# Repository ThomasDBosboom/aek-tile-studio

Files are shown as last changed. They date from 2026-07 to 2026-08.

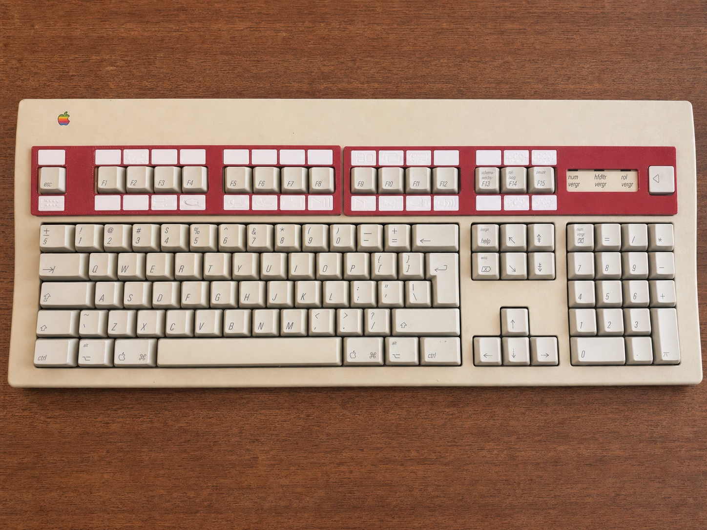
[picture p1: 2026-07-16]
assets/images/aek-tile-studio-installed-prototype-v2.jpg

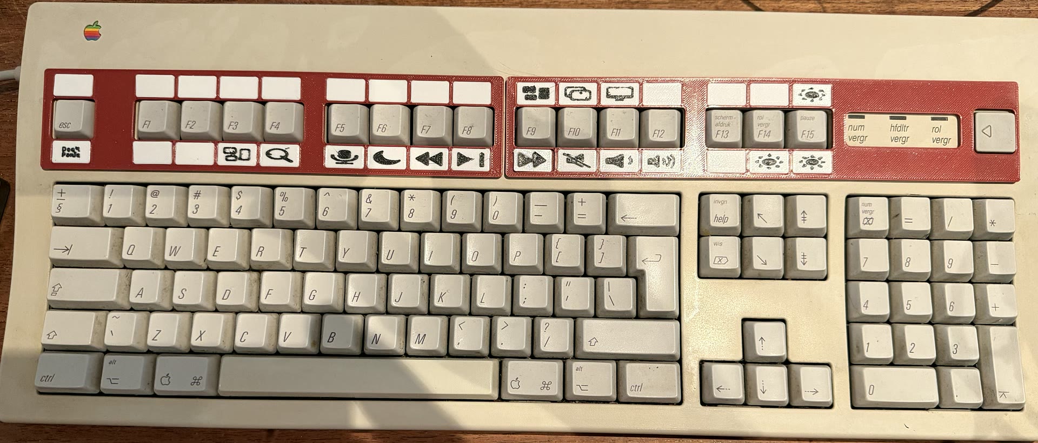
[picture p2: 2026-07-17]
assets/images/aek-tile-studio-installed-prototype-v3.jpg

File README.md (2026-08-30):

# AEK Tile Studio

A static, client-side prototype for arranging and generating modular legend
tiles for the Apple Extended Keyboard II.

##public page

https://thomasdbosboom.github.io/aek-tile-studio/

## Run your own - Local preview

Run a static HTTP server from this directory; ES modules and SVG loading do
not work reliably through `file://` URLs.

```sh
python3 -m http.server 8080 --directory site
```

Then open <http://localhost:8080>.

## Geometry

- Tile: 17.4 × 10.2 × 1.7 mm
- Medium fit: 0.10 mm clearance per side in the rev10 frame
- Top chamfer: 0.25 mm
- Default symbol relief: 0.40 mm

The browser generator exports binary STL using Three.js. Glyph and tile meshes
overlap slightly so slicers treat them as one printable body. Validate a test
tile in your slicer before committing to a full plate.

## Publishing

The `site` directory is suitable for GitHub Pages. It has no build step and no
server-side component.

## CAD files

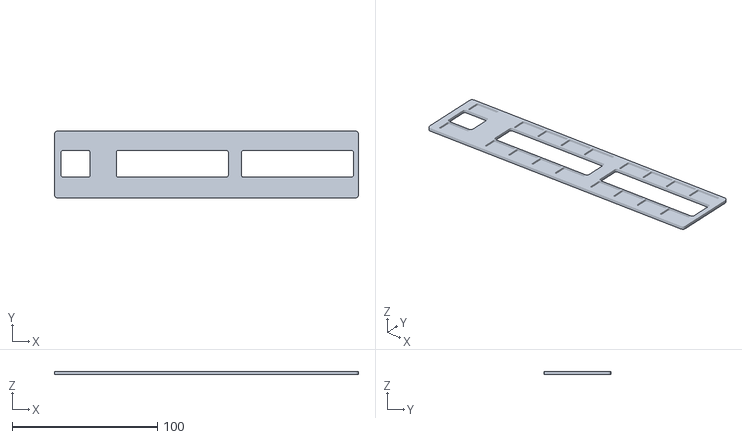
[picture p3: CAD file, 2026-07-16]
assets/frames/AEK_left_ESC_F1-F8_frame_rev10.stl
209.0 x 46.0 x 2.20

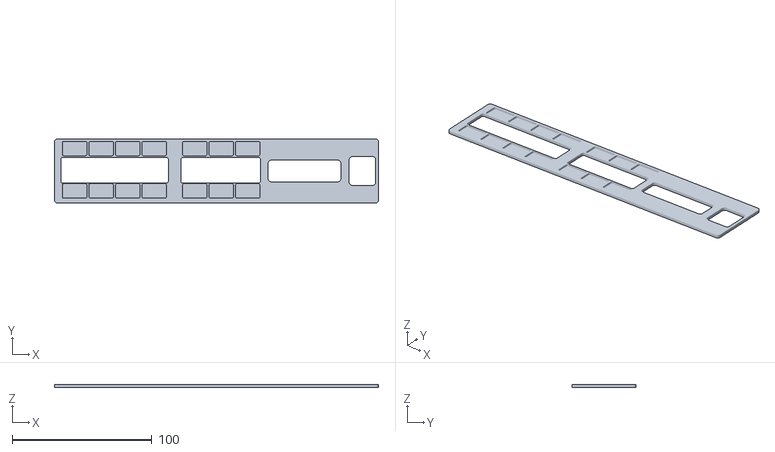
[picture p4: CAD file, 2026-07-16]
assets/frames/AEK_right_F9-F15_lights_layer_frame_rev10.stl
232.0 x 46.0 x 2.20

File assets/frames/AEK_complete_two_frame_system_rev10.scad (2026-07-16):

$fn=64;
part="right";
frame_h=46.0; frame_t=2.2; pocket_floor=0.6; opening_h=18.5;
slot_w=17.6; slot_h=10.4; slot_r=1.1; edge_y=2.6;
side_clearance=0.1; insert_t=1.7;
left_w=209.0; right_w=232.0;
module rr(w,h,r){ offset(r=r) square([w-2*r,h-2*r]); }
module pocket_at(cx,y){ translate([cx-slot_w/2,y,pocket_floor]) linear_extrude(frame_t-pocket_floor+0.1) rr(slot_w,slot_h,slot_r); }
module left_frame(){
 xesc=4; escw=20; xf1=xesc+escw+18; xf5=xf1+77+9;
 centres=concat([xesc+escw/2],[for(i=[0:3]) xf1+9.5+19*i],[for(i=[0:3]) xf5+9.5+19*i]);
 openings=[[xesc,(frame_h-opening_h)/2,escw,opening_h,1.5],[xf1,(frame_h-opening_h)/2,77,opening_h,1.5],[xf5,(frame_h-opening_h)/2,77,opening_h,1.5]];
 difference(){
  linear_extrude(frame_t) rr(left_w,frame_h,2);
  for(o=openings) translate([o[0],o[1],-.1]) linear_extrude(frame_t+.2) rr(o[2],o[3],o[4]);
  for(cx=centres) for(y=[edge_y,frame_h-edge_y-slot_h]) pocket_at(cx,y);
 }
}
module right_frame(){
 xf9=4; xf13=90; xlights=153; xlayer=211;
 centres=concat([for(i=[0:3]) xf9+9.5+19*i],[for(i=[0:2]) xf13+9.5+19*i]);
 openings=[
  [xf9,(frame_h-opening_h)/2,77,opening_h,1.5],
  [xf13,(frame_h-opening_h)/2,57,opening_h,1.5],
  [xlights,(frame_h-opening_h)/2+1.5,52,15.5,2],
  [xlayer,(frame_h-opening_h)/2-1,19,20.5,2]
 ];
 difference(){
  linear_extrude(frame_t) rr(right_w,frame_h,2);
  for(o=openings) translate([o[0],o[1],-.1]) linear_extrude(frame_t+.2) rr(o[2],o[3],o[4]);
  for(cx=centres) for(y=[edge_y,frame_h-edge_y-slot_h]) pocket_at(cx,y);
 }
}
module icon_insert(){ linear_extrude(insert_t) rr(slot_w-2*side_clearance,slot_h-2*side_clearance,1); }
if(part=="left") left_frame(); else if(part=="right") right_frame(); else icon_insert();

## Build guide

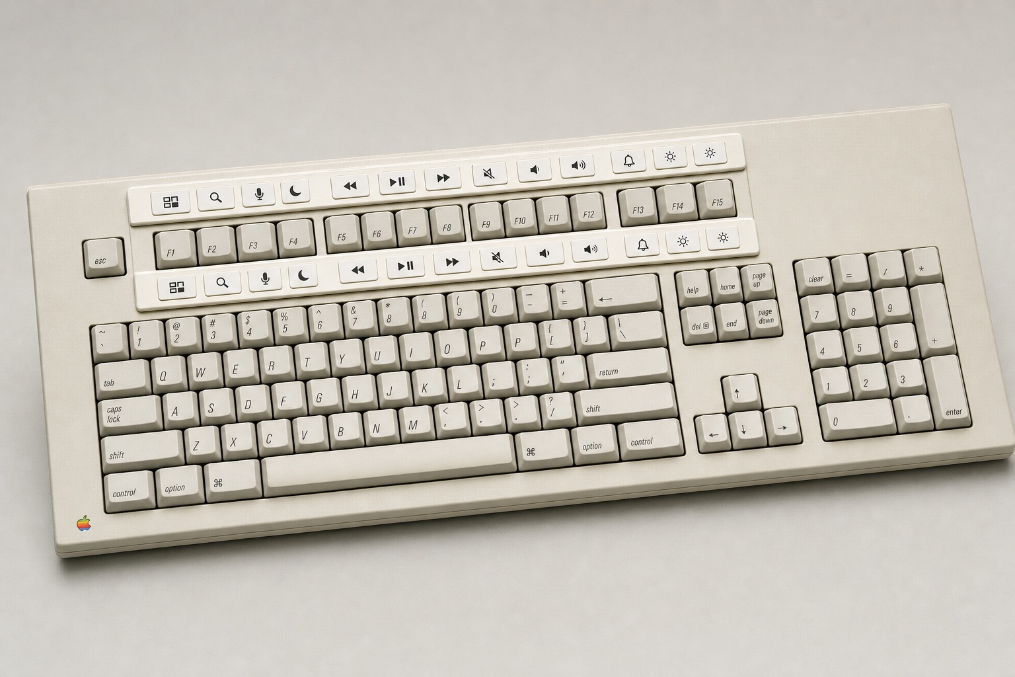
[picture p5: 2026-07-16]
assets/images/aek-tile-studio-installed-v1.jpg

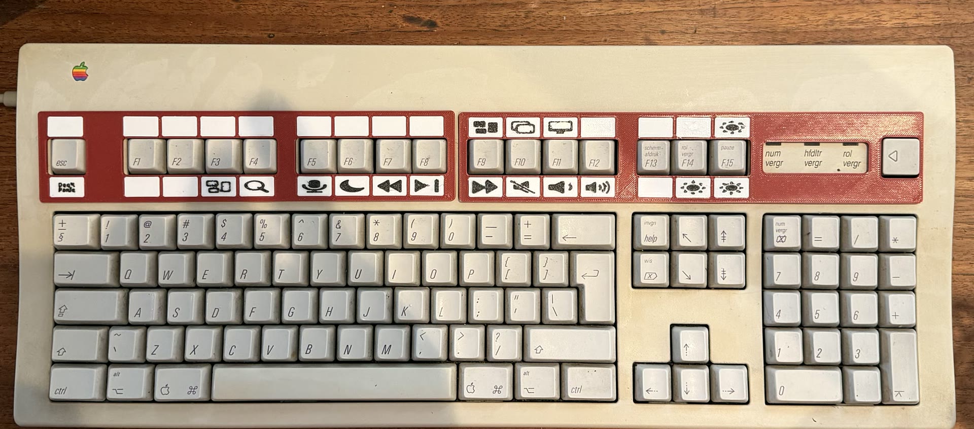
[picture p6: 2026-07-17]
assets/images/aek-tile-studio-installed-prototype-v4.jpg

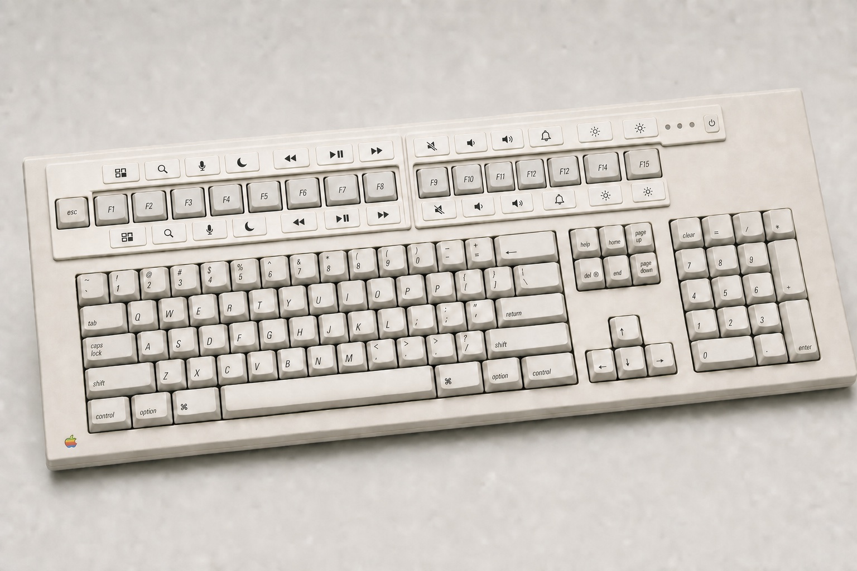
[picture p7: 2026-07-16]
assets/images/aek-tile-studio-installed-v2.jpg

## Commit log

2026-07-16 Launch AEK Tile Studio prototype
    [AEK_complete_two_frame_system_rev10.scad, AEK_left_ESC_F1-F8_frame_rev10.stl, AEK_right_F9-F15_lights_layer_frame_rev10.stl]
2026-07-16 Correct hero frame split and controls
2026-07-16 Polish installed prototype photograph
2026-07-17 Update installed prototype photo
2026-07-17 Use clearer installed prototype photo
